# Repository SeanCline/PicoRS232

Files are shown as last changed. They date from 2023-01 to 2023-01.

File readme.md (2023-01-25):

# PicoRS232

>⚠ I haven't had this PCB design manufactured yet so there may be bugs. Here be dragons.

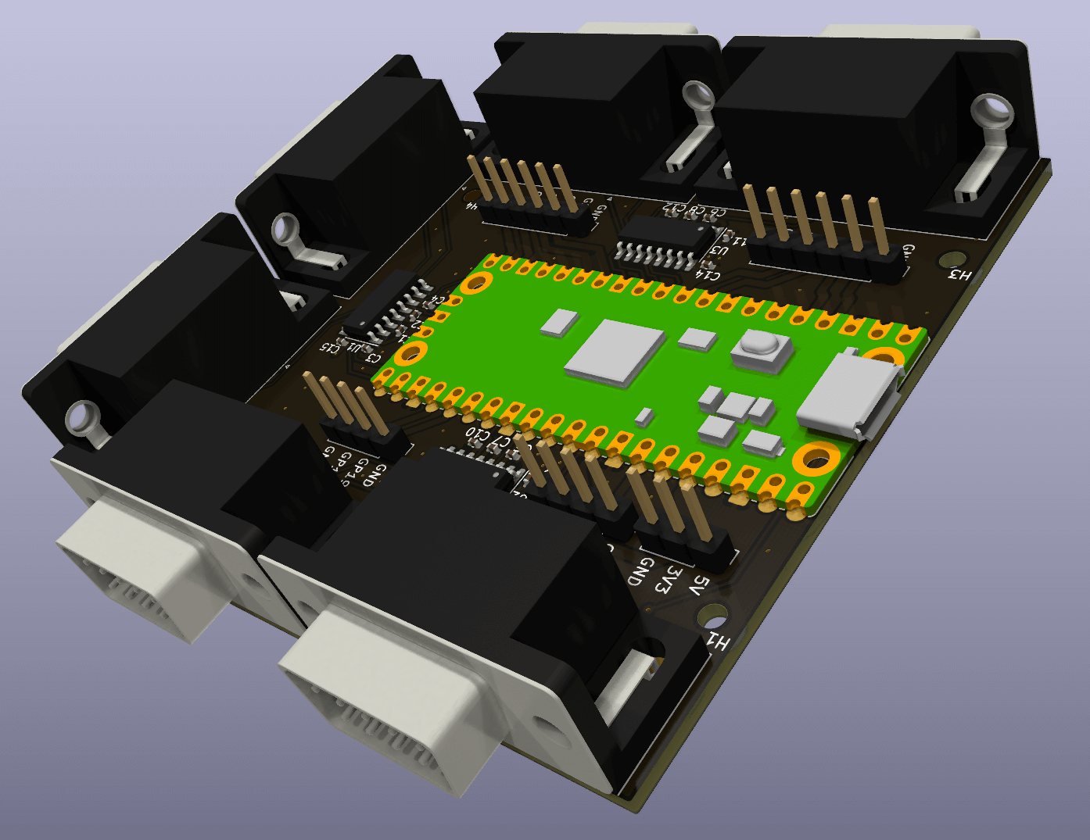
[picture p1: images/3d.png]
3D render of PicoRS232 board


This PCB connects 6 RS232 UART ports to a Raspberry Pi Pico.
 1) Two ports are connected to the RP2040's 2 hardware UARTs.
 2) Four more ports are connected to the RP2040's PIO drivers for software UART.

The TX/RX pins line up with those from the [Pico UART Bridge](https://github.com/harrywalsh/pico-hw_and_pio-uart-gridge/tree/HW_and_pio_uarts) firmware so that firmware should work out-of-the-box.

Note: Flow control is not supported in this design. Only TX/RX are connected to each port. This was done to keep the BOM low and software simple.

## Schematic

Schematic

## Board

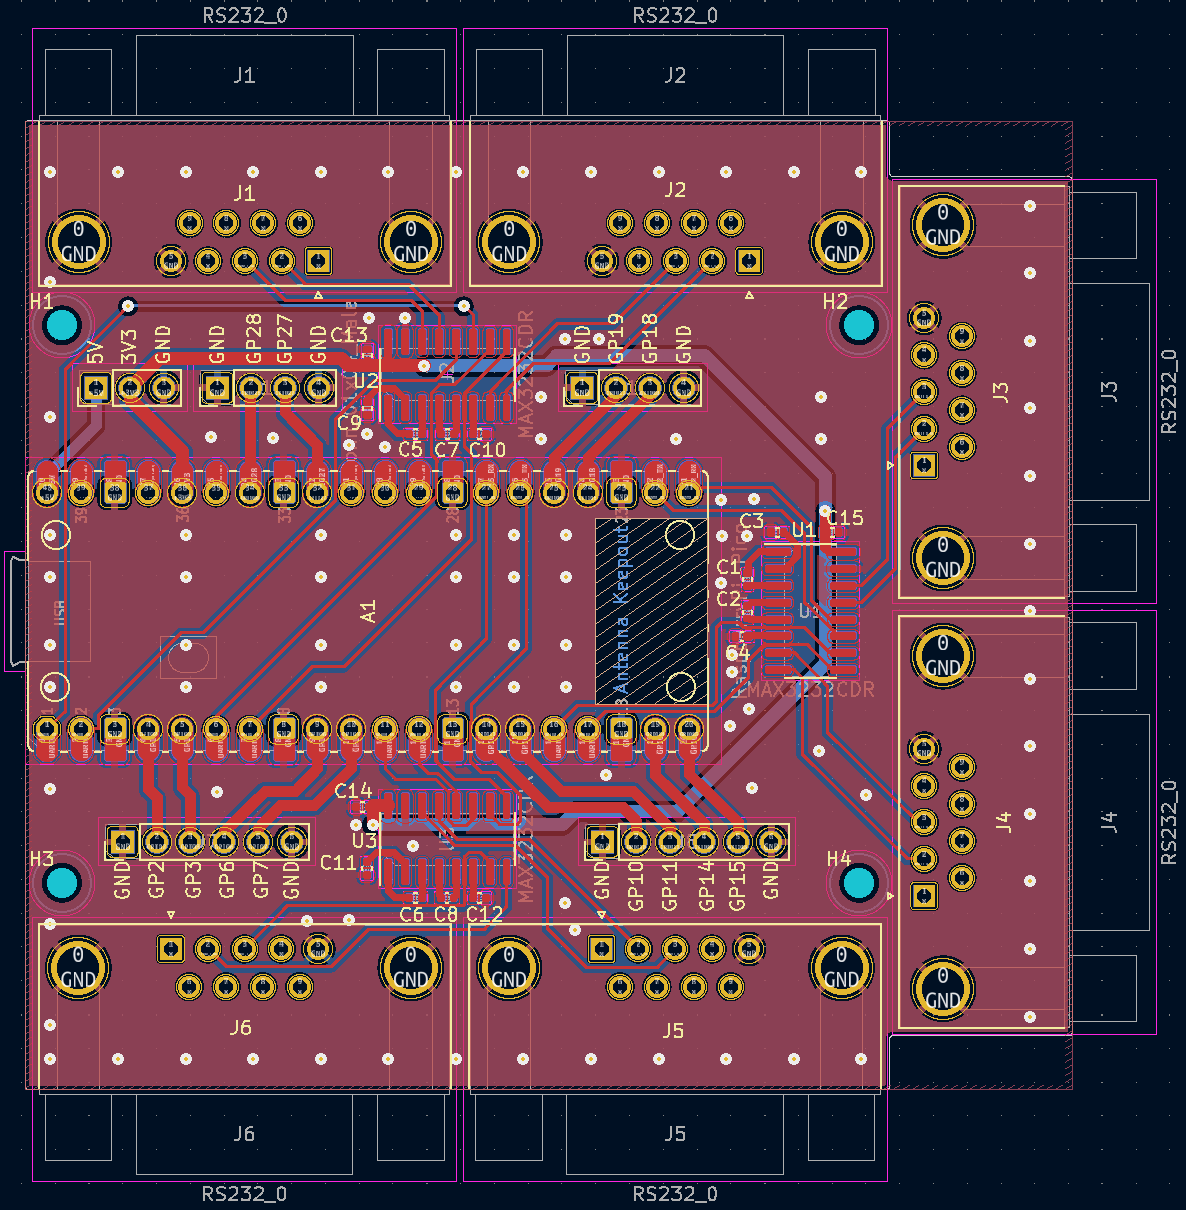
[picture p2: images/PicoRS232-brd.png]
2D board design


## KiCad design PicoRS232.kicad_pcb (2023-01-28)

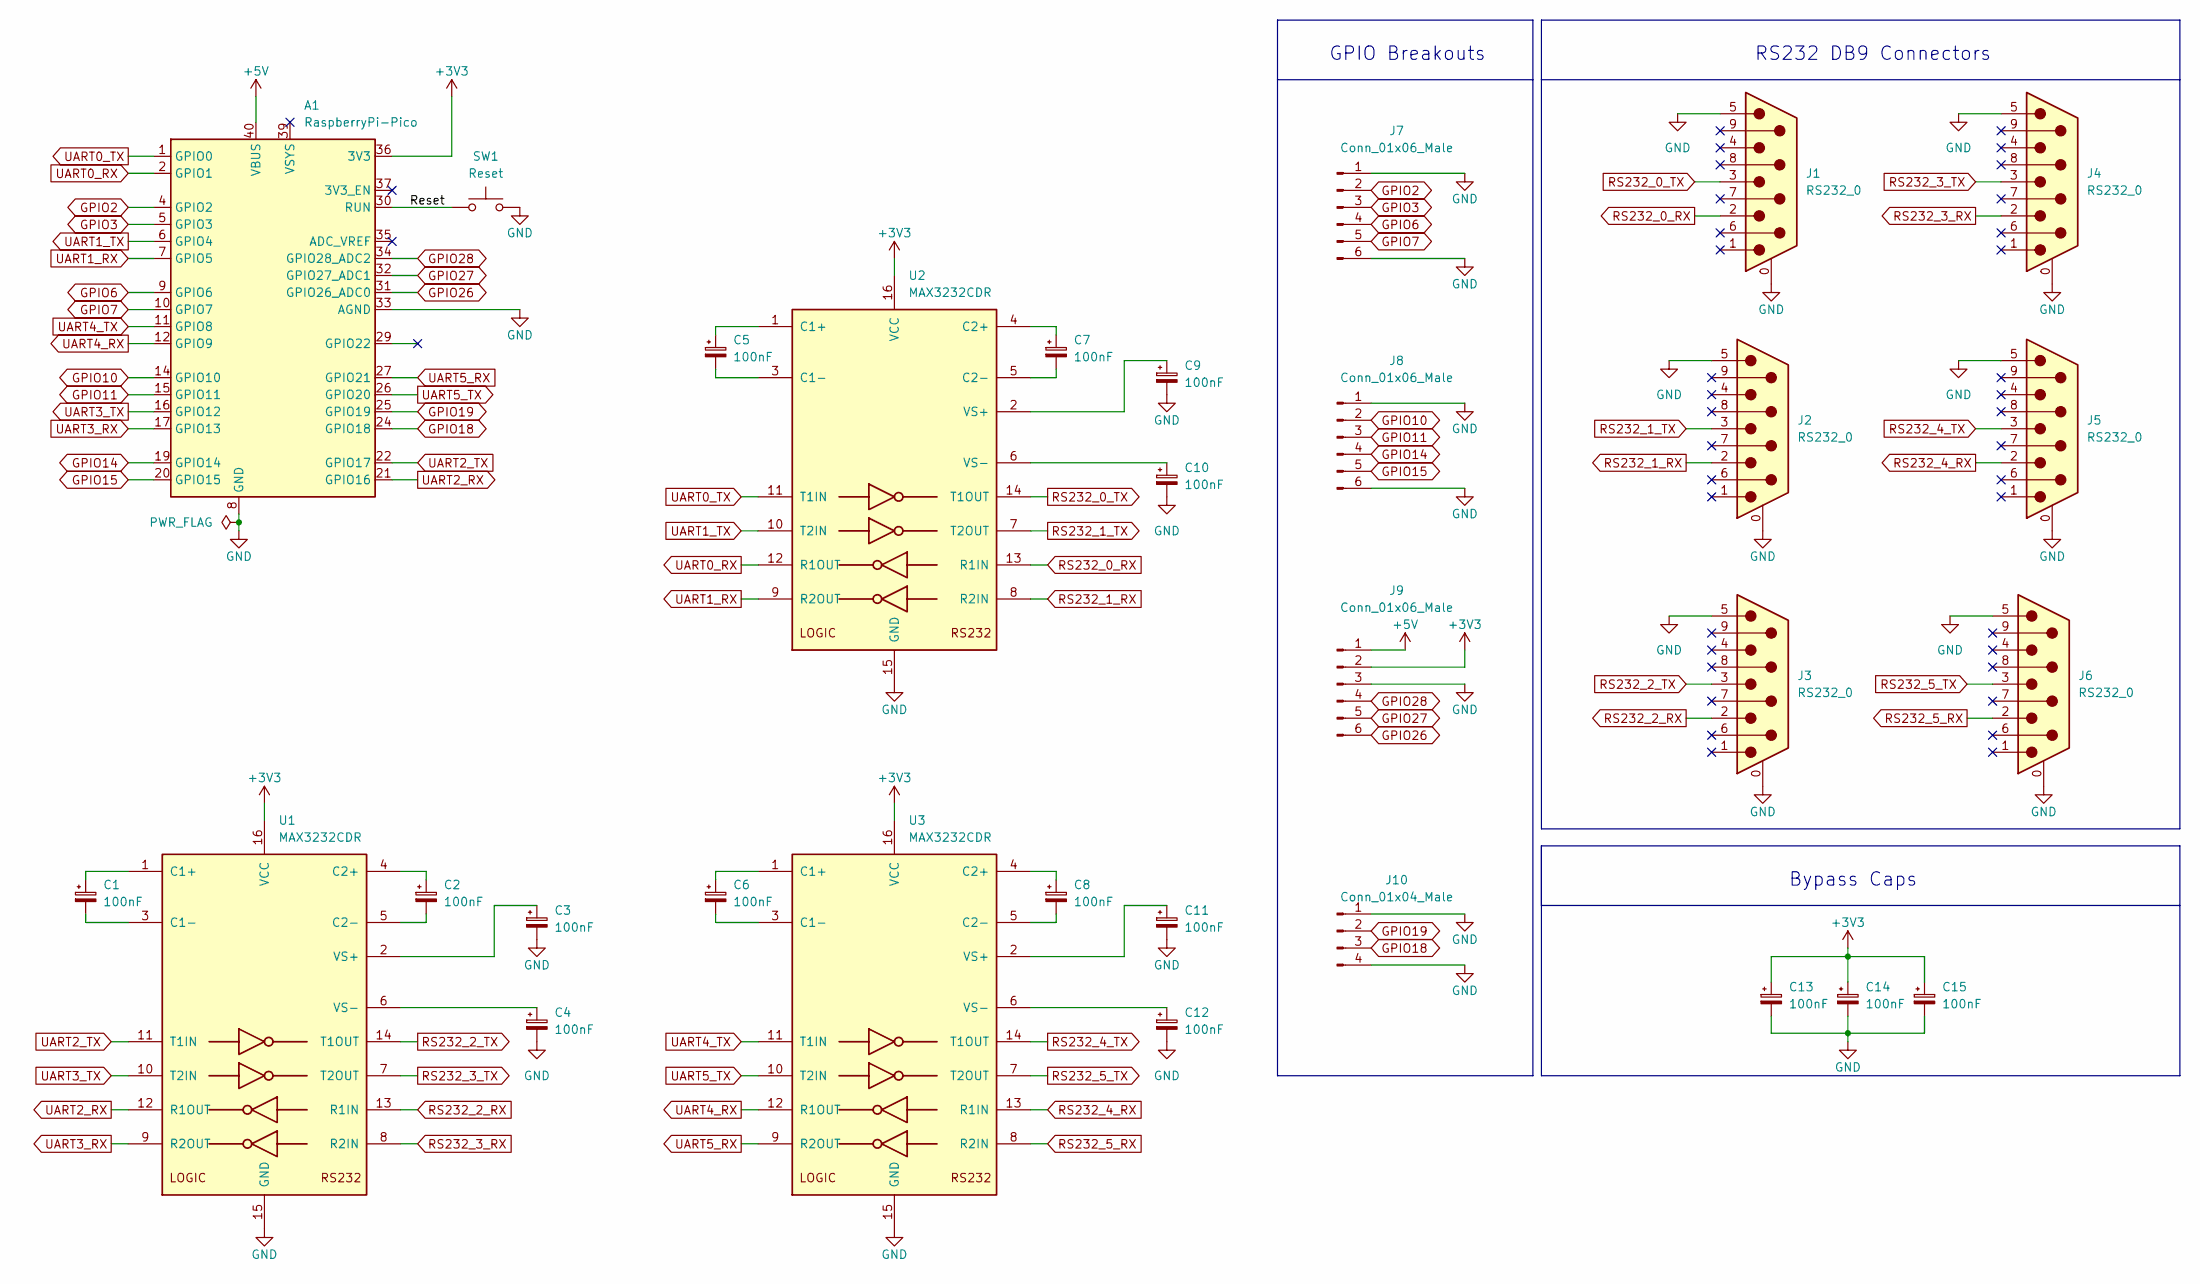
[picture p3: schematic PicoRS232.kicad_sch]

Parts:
A1: RaspberryPi-Pico; Raspberry_Pi_Pico_SMT_THT
C1, C2, C3, C4, C5, C6, C7, C8, C9, C10, C11, C12, C13, C14, C15: 100nF; C_0402_1005Metric; LCSC C307331
J1, J2, J3, J4, J5, J6: RS232_0; DSUB-9_Male_Horizontal_P2.77x2.84mm_EdgePinOffset7.70mm_Hou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; LCSC C141880
J7, J8, J9: Conn_01x06_Male; PinHeader_1x06_P2.54mm_Vertical; LCSC C225481
J10: Conn_01x04_Male; PinHeader_1x04_P2.54mm_Vertical; LCSC C225479
SW1: Reset; SW_SPST_SKQG_WithStem; LCSC C318889
U1, U2, U3: MAX3232CDR; SOIC-16_3.9x9.9mm_P1.27mm; LCSC C45843

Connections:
+3V3: A1.36 (3V3), C13.1, C14.1, C15.1, J9.2, U1.16 (VCC), U2.16 (VCC), U3.16 (VCC)
+5V: A1.40 (VBUS), J9.1
/Reset: A1.30 (RUN), SW1.1
GND: A1.3 (GND), A1.8 (GND), A1.13 (GND), A1.18 (GND), A1.23 (GND), A1.28 (GND), A1.33 (AGND), A1.38 (GND), C3.2, C4.2, C9.2, C10.2, C11.2, C12.2, C13.2, C14.2, C15.2, J1.0 (PAD), J1.5, J2.0 (PAD), J2.5, J3.0 (PAD), J3.5, J4.0 (PAD), J4.5, J5.0 (PAD), J5.5, J6.0 (PAD), J6.5, J7.1, J7.6, J8.1, J8.6, J9.3, J10.1, J10.4, SW1.2, U1.15 (GND), U2.15 (GND), U3.15 (GND)
GPIO2: A1.4 (GPIO2), J7.2
GPIO3: A1.5 (GPIO3), J7.3
GPIO6: A1.9 (GPIO6), J7.4
GPIO7: A1.10 (GPIO7), J7.5
GPIO10: A1.14 (GPIO10), J8.2
GPIO11: A1.15 (GPIO11), J8.3
GPIO14: A1.19 (GPIO14), J8.4
GPIO15: A1.20 (GPIO15), J8.5
GPIO18: A1.24 (GPIO18), J10.3
GPIO19: A1.25 (GPIO19), J10.2
GPIO26: A1.31 (GPIO26_ADC0), J9.6
GPIO27: A1.32 (GPIO27_ADC1), J9.5
GPIO28: A1.34 (GPIO28_ADC2), J9.4
unnamed: C1.1, U1.1 (C1+)
unnamed: C1.2, U1.3 (C1-)
unnamed: C2.1, U1.4 (C2+)
unnamed: C2.2, U1.5 (C2-)
unnamed: C3.1, U1.2 (VS+)
unnamed: C4.1, U1.6 (VS-)
unnamed: C5.1, U2.1 (C1+)
unnamed: C5.2, U2.3 (C1-)
unnamed: C6.1, U3.1 (C1+)
unnamed: C6.2, U3.3 (C1-)
unnamed: C7.1, U2.4 (C2+)
unnamed: C7.2, U2.5 (C2-)
unnamed: C8.1, U3.4 (C2+)
unnamed: C8.2, U3.5 (C2-)
unnamed: C9.1, U2.2 (VS+)
unnamed: C10.1, U2.6 (VS-)
unnamed: C11.1, U3.2 (VS+)
unnamed: C12.1, U3.6 (VS-)
RS232_0_RX: J1.2, U2.13 (R1IN)
RS232_0_TX: J1.3, U2.14 (T1OUT)
RS232_1_RX: J2.2, U2.8 (R2IN)
RS232_1_TX: J2.3, U2.7 (T2OUT)
RS232_2_RX: J3.2, U1.13 (R1IN)
RS232_2_TX: J3.3, U1.14 (T1OUT)
RS232_3_RX: J4.2, U1.8 (R2IN)
RS232_3_TX: J4.3, U1.7 (T2OUT)
RS232_4_RX: J5.2, U3.13 (R1IN)
RS232_4_TX: J5.3, U3.14 (T1OUT)
RS232_5_RX: J6.2, U3.8 (R2IN)
RS232_5_TX: J6.3, U3.7 (T2OUT)
UART0_RX: A1.2 (GPIO1), U2.12 (R1OUT)
UART0_TX: A1.1 (GPIO0), U2.11 (T1IN)
UART1_RX: A1.7 (GPIO5), U2.9 (R2OUT)
UART1_TX: A1.6 (GPIO4), U2.10 (T2IN)
UART2_RX: A1.21 (GPIO16), U1.12 (R1OUT)
UART2_TX: A1.22 (GPIO17), U1.11 (T1IN)
UART3_RX: A1.17 (GPIO13), U1.9 (R2OUT)
UART3_TX: A1.16 (GPIO12), U1.10 (T2IN)
UART4_RX: A1.12 (GPIO9), U3.12 (R1OUT)
UART4_TX: A1.11 (GPIO8), U3.11 (T1IN)
UART5_RX: A1.27 (GPIO21), U3.9 (R2OUT)
UART5_TX: A1.26 (GPIO20), U3.10 (T2IN)

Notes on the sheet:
Bypass Caps
GPIO Breakouts
RS232 DB9 Connectors

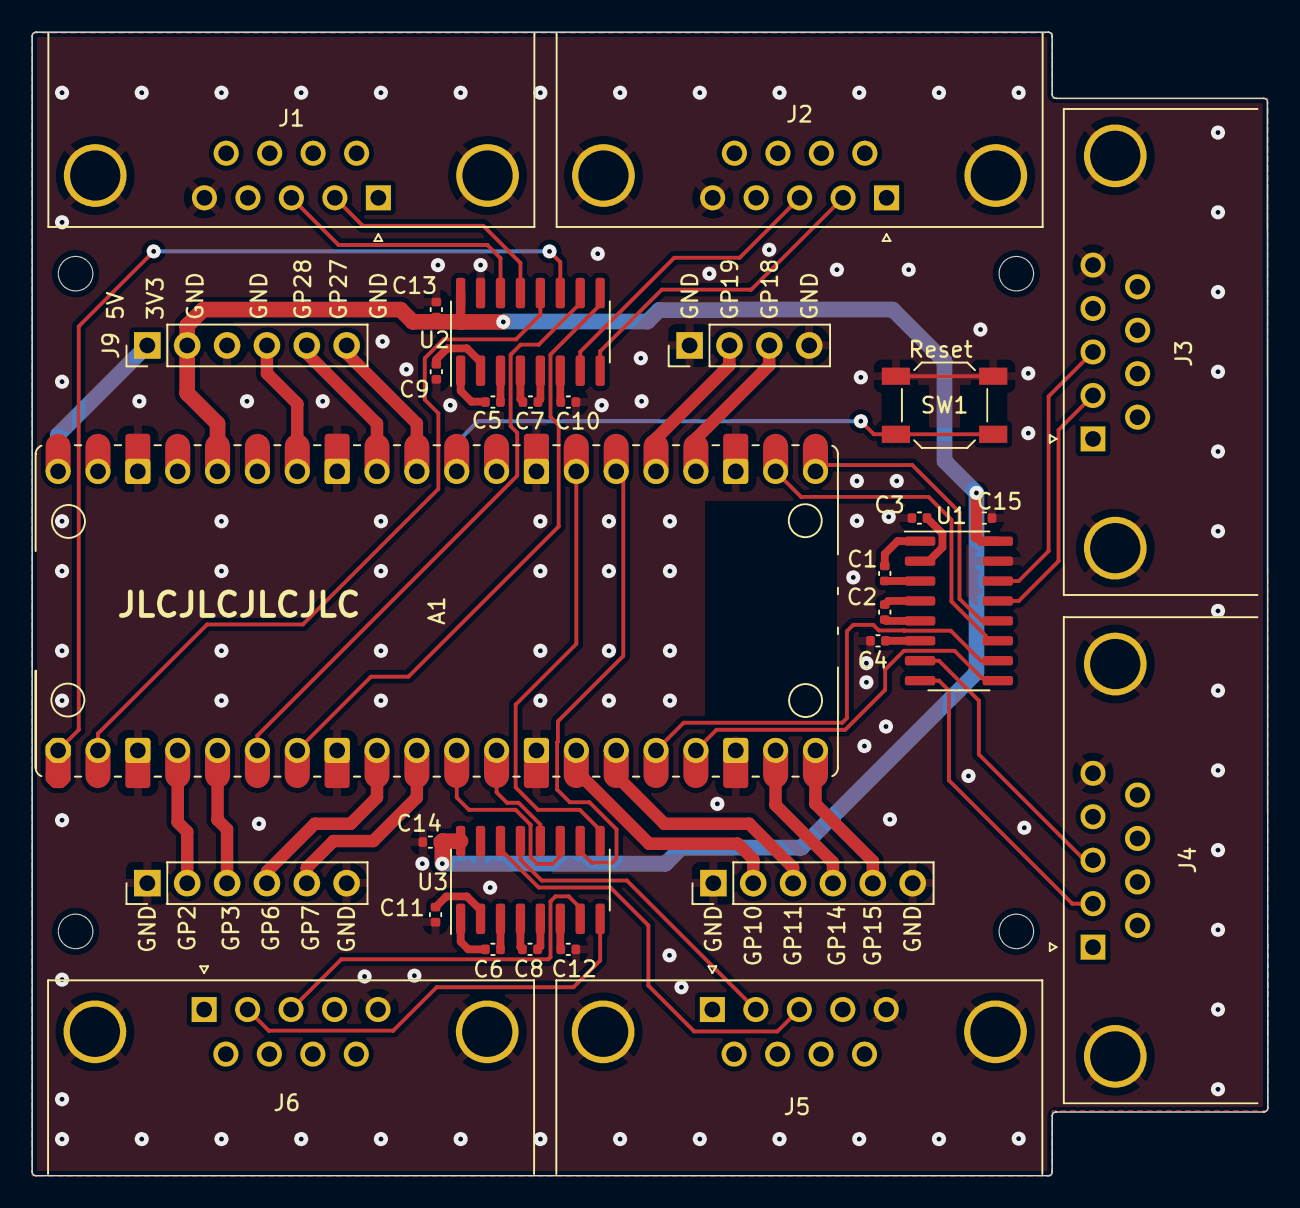
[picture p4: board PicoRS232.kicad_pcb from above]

Board: 2 copper layers, 78.7 x 72.9 mm, 34 parts (0 on the bottom side), 59 nets.

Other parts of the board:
H1, H2, H3, H4: MountingHole_2.2mm_M2

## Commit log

2023-01-19 Initial Commit.
    Design is largely done, but needs lots of review before manufacture.
    [PicoRS232.kicad_pcb, PicoRS232.kicad_sch]
2023-01-19 Break out unused GPIO pins to headers.
    [PicoRS232.kicad_pcb, PicoRS232.kicad_sch]
2023-01-22 Organize schematic and add mounting holes.
    [PicoRS232.kicad_pcb, PicoRS232.kicad_sch]
2023-01-25 Silkscreen and cosmetic improvements to PCB.
    [PicoRS232.kicad_pcb]
2023-01-26 Add a reset button and merge two pin headers.
    [PicoRS232.kicad_pcb, PicoRS232.kicad_sch]
2023-01-27 Change reset button to one JLCPCB has in stock.
    [PicoRS232.kicad_pcb, PicoRS232.kicad_sch]
2023-01-28 Add silkscreen with name, version, and url.
    Also, add pin header part numbers, but leave them out of the BOM.
    [PicoRS232.kicad_pcb, PicoRS232.kicad_sch]
